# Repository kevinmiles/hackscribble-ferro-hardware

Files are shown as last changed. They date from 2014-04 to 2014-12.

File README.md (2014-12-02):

Hackscribble FRAM Hardware
==========================

#### *PCB designs for connecting Fujitsu MB85RS Ferroelectric memory (FRAM) to Arduino and LPCXpresso boards.*

Created on 20 April 2014 by Ray Benitez  
Last modified on 1 December 2014 by Ray Benitez		
  
These hardware designs are licensed by Ray Benitez under the Creative Commons Attribution-Sharealike 4.0 International License.
	
git@hackscribble.com | http://www.hackscribble.com | http://www.twitter.com/hackscribble

### About the hardware

#### Level converter circuits

These circuit snippets connect 3.3V MB85RS FRAM chips to 5V Arduino inputs / outputs.  

Two design approaches are shown:

1. Discrete design using BSS108 FETs, following the approach used by the Adafruit level converter.

2. Integrated design using TXB0104 to reduce PCB space required. 

The designs are in Eagle format.

#### Mini-shield

The mini-shield allows up to three 3.3V FRAMS to be connected to an Arduino (or an LPCXPresso board).  It uses an extended version of the integrated circuit snippet (above) using a TXB0108. The board has been tested with Arduino Uno and LPCXpresso 11U68 boards.

The design is in KiCad format.

The supply voltage for the Arduino / LPCXpresso side of the level converter is taken from the IOREF output of the Arduino / LPCXpresso.  This automatically adjusts for 3.3V or 5V boards.

The REVISION B board also includes test points for monitoring the SPI bus.
<br>

<hr>

### Change history

#### 1 December 2014

Added mini-shield REVISION C "slim" version.

#### 5 November 2014

Upgraded mini-shield to REVISION B.

#### 1 November 2014

Added mini-shield REVISION A.

#### 20 April 2014

Initial release of level converter circuits REVISION A.

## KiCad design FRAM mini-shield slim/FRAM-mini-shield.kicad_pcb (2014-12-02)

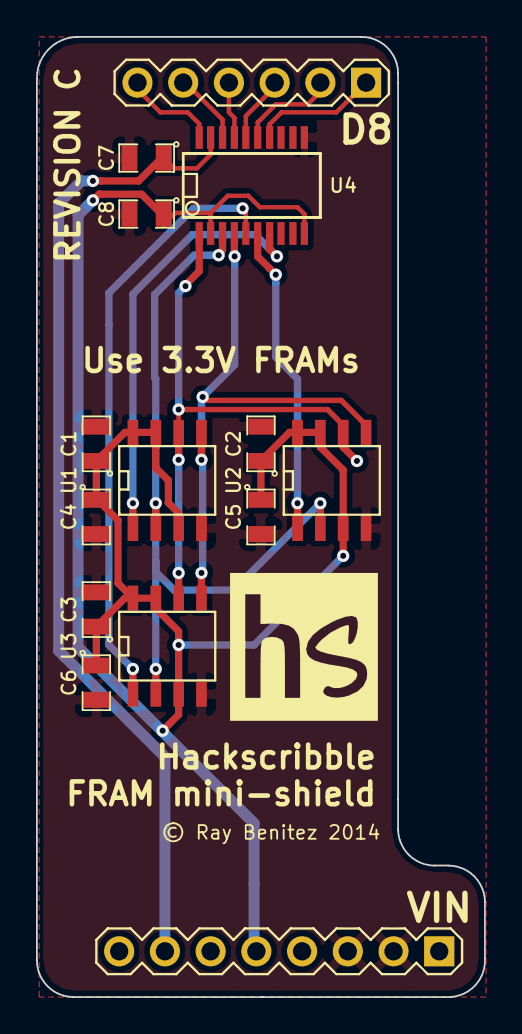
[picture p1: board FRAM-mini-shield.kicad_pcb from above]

Board: 2 copper layers, 24.9 x 53.3 mm, 14 parts (0 on the bottom side), 15 nets.

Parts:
C1, C2, C3, C7, C8: 100nF; SMD-0805
C4, C5, C6: 10uF; SMD-0805
HDR1: AB2_HDR08-1; AB2_HDR_M08-1V
HDR2: AB2_HDR06-1; AB2_HDR_M06-1V
U1, U2, U3: MB85RS1MT; SOIC-8-W
U4: TXB0108; SSOP-20

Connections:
+3.3V: C1.1, C2.1, C3.1, C4.1, C5.1, C6.1, C8.1, HDR1.5, U1.3, U1.7, U1.8, U2.3, U2.7, U2.8, U3.3, U3.7, U3.8, U4.2, U4.10
GND: C1.2, C2.2, C3.2, C4.2, C5.2, C6.2, C7.2, C8.2, HDR1.2, HDR1.3, U1.4, U2.4, U3.4, U4.11
unnamed: C7.1, HDR1.7, U4.19
unnamed: HDR2.1, U4.14
unnamed: HDR2.2, U4.15
unnamed: HDR2.3, U4.16
unnamed: HDR2.4, U4.17
unnamed: HDR2.5, U4.18
unnamed: HDR2.6, U4.20
unnamed: U1.1, U4.7
unnamed: U1.2, U2.2, U3.2, U4.3
unnamed: U1.5, U2.5, U3.5, U4.4
unnamed: U1.6, U2.6, U3.6, U4.1
unnamed: U2.1, U4.6
unnamed: U3.1, U4.5

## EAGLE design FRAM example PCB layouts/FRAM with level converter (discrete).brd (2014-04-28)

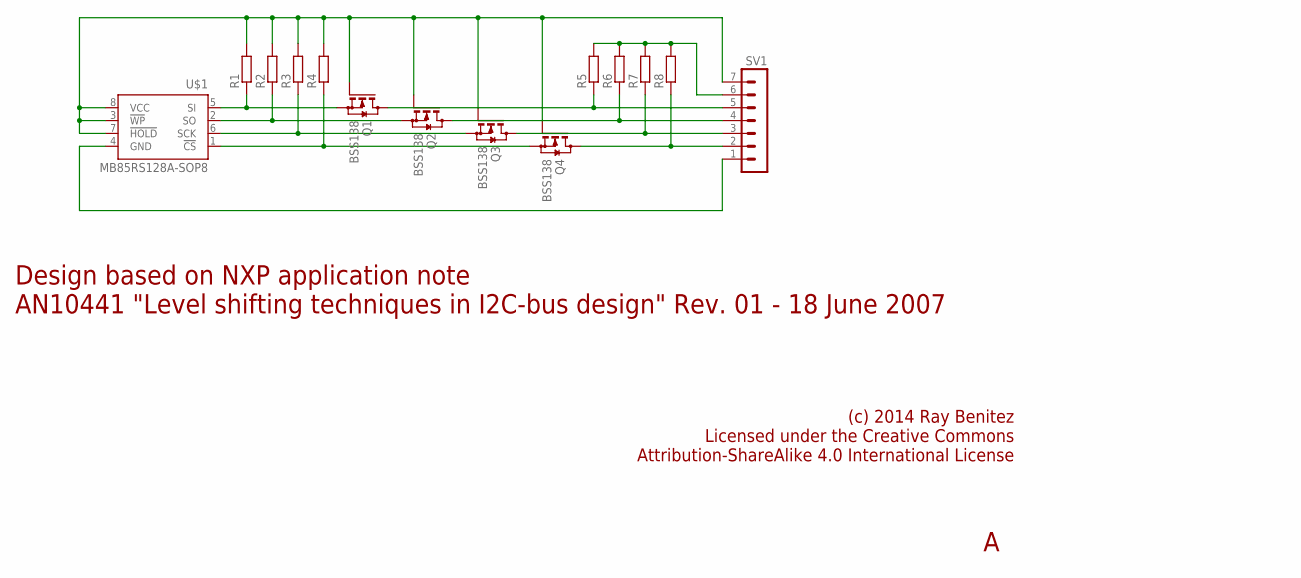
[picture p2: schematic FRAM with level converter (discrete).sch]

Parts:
Q1, Q2, Q3, Q4: BSS138; SOT23
R1, R2, R3, R4, R5, R6, R7, R8: R-EU_R0805; R0805
SV1: MA07-1
U$1: MB85RS128A-SOP8; SO08

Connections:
GND: SV1.1, U$1.4 (GND)
unnamed: Q1.2 (S), R1.1, U$1.5 (SI)
unnamed: Q2.2 (S), R2.1, U$1.2 (SO)
unnamed: Q3.2 (S), R3.1, U$1.6 (SCK)
unnamed: Q4.2 (S), R4.1, U$1.1 (!CS)
unnamed: Q1.1 (G), Q2.1 (G), Q3.1 (G), Q4.1 (G), R1.2, R2.2, R3.2, R4.2, SV1.7, U$1.3 (!WP), U$1.7 (!HOLD), U$1.8 (VCC)
unnamed: Q4.3 (D), R8.1, SV1.2
unnamed: Q3.3 (D), R7.1, SV1.3
unnamed: Q2.3 (D), R6.1, SV1.4
unnamed: Q1.3 (D), R5.1, SV1.5
unnamed: R5.2, R6.2, R7.2, R8.2, SV1.6

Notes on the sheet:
(c) 2014 Ray Benitez Licensed under the Creative Commons Attribution-ShareAlike 4.0 International License
Design based on NXP application note AN10441 "Level shifting techniques in I2C-bus design" Rev. 01 - 18 June 2007

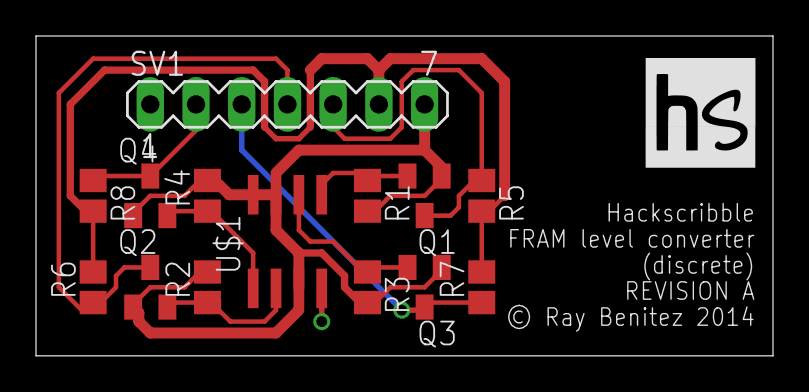
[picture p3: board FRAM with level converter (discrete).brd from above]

Board: 2 copper layers, 40.9 x 17.8 mm, 14 parts (0 on the bottom side), 11 nets.

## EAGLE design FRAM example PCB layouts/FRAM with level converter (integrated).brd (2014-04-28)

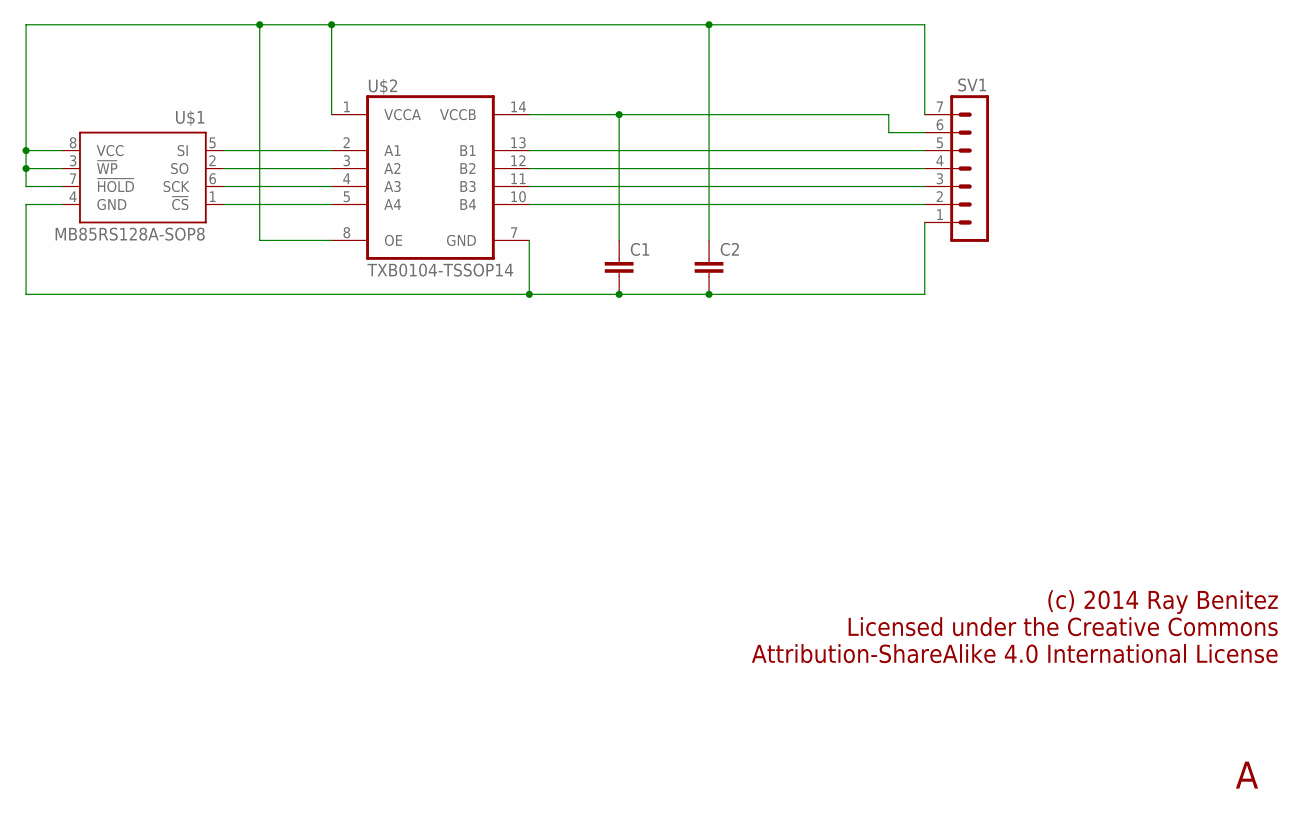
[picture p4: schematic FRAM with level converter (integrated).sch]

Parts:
C1, C2: C-EUC0805; C0805
SV1: MA07-1
U$1: MB85RS128A-SOP8; SO08
U$2: TXB0104-TSSOP14; TSSOP14

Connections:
GND: C1.2, C2.2, SV1.1, U$1.4 (GND), U$2.7 (GND)
unnamed: SV1.5, U$2.13 (B1)
unnamed: SV1.4, U$2.12 (B2)
unnamed: U$1.5 (SI), U$2.2 (A1)
unnamed: U$1.2 (SO), U$2.3 (A2)
unnamed: C2.1, SV1.7, U$1.3 (!WP), U$1.7 (!HOLD), U$1.8 (VCC), U$2.1 (VCCA), U$2.8 (OE)
unnamed: SV1.2, U$2.10 (B4)
unnamed: SV1.3, U$2.11 (B3)
unnamed: U$1.6 (SCK), U$2.4 (A3)
unnamed: U$1.1 (!CS), U$2.5 (A4)
unnamed: C1.1, SV1.6, U$2.14 (VCCB)

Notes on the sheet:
(c) 2014 Ray Benitez Licensed under the Creative Commons Attribution-ShareAlike 4.0 International License

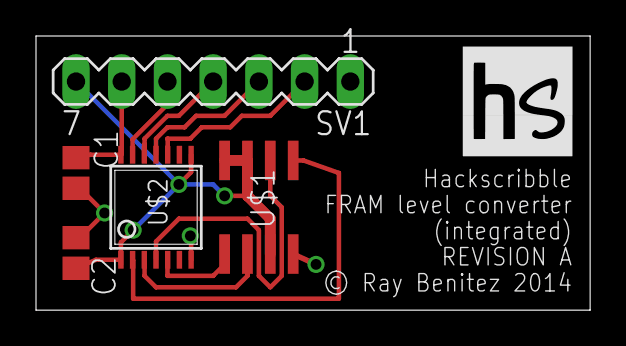
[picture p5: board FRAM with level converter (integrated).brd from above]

Board: 2 copper layers, 30.8 x 15.2 mm, 5 parts (0 on the bottom side), 11 nets.

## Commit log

2014-04-28 Revision A.
    [FRAM with level converter (discrete).brd, FRAM with level converter (discrete).sch, FRAM with level converter (integrated).brd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]
2014-11-01 2014-11-01 release.
    [FRAM with level converter (discrete).brd, FRAM with level converter (discrete).sch, FRAM with level converter (integrated).brd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]
2014-11-05 2014-11-05 release.
    [FRAM-mini-shield.kicad_pcb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]
2014-12-02 2014-12-02 release.
    [FRAM-mini-shield-B_Cu.gbl, FRAM-mini-shield-B_Mask.gbs, FRAM-mini-shield-B_SilkS.gbo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]

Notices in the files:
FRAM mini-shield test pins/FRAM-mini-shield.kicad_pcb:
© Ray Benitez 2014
